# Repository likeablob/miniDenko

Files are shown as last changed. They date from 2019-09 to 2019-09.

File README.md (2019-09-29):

<p align="center">
  
</p>

# miniDenko - A portable messaging device
`miniDenko` (Denko = 電光 is from "an electric scoreboard" in Japanese) is a portable messaging device.

Or LED Matrix + ESP8266 + MPU6050 + Modern Web framework(Vue.js + Buefy) = A hackable LED messaging platform

<p align="center">
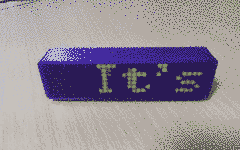
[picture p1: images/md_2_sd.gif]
  
</p>

## Features
- Edit & save your message and show it up instantly.(Sub-second booting)
  - Also supports Japanese characters thanks to [Arduino-misakiUTF16](https://github.com/Tamakichi/Arduino-misakiUTF16) lib written by [[Tamakichi]](https://github.com/Tamakichi) san.
- Easily connectable with Phones, Laptops, etc. via WiFi.
  - Supports `STA`, `AP`, `AP_STA` modes to collaborate with the devices.
- Made from easily-obtainable parts. (See [#BOM](#BOM))
- Its [portable and slim shape](./openscad/minidenko-case-body-opaque.stl) fits in your (large) pocket.

- And as a latest gadget should be, equipped with the **Type-C** charging port.

## Project structure
- [`pio/`](./pio) - code for the firmware(PlatformIO)
- [`pio/webui/`](./pio/webui) - code for the WebUI(Vue.js + Buefy)
- [`kicad/`](./kicad) - PCB design (KiCad)
- [`gerber/`](./gerber) - PCB gerber files (KiCad)
- [`openscad/`](./openscad) - models for the 3D-printable case. (OpenSCAD)

## Gallery
| | Descriptions |
| --- | --- |
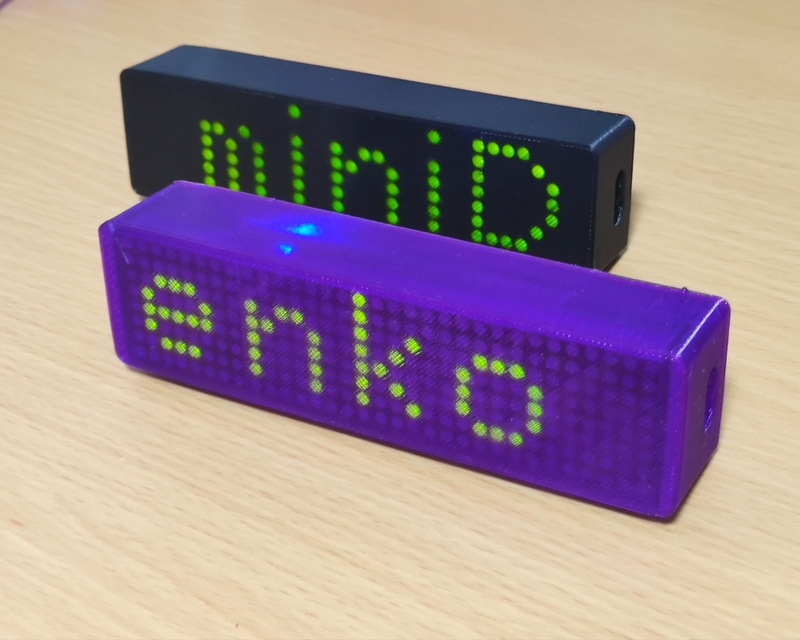
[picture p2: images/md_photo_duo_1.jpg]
|  | Front view |
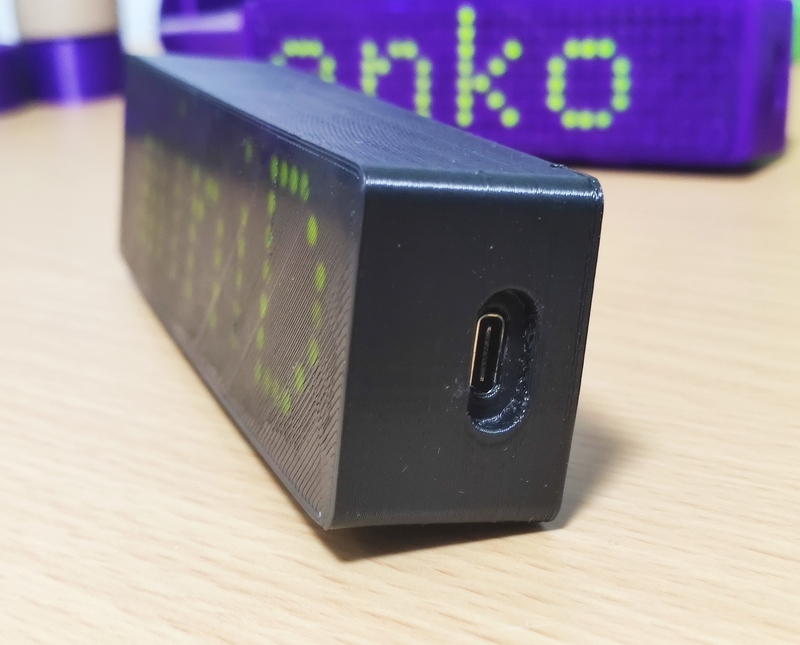
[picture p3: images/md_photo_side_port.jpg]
|  | Side view (Charging port) |
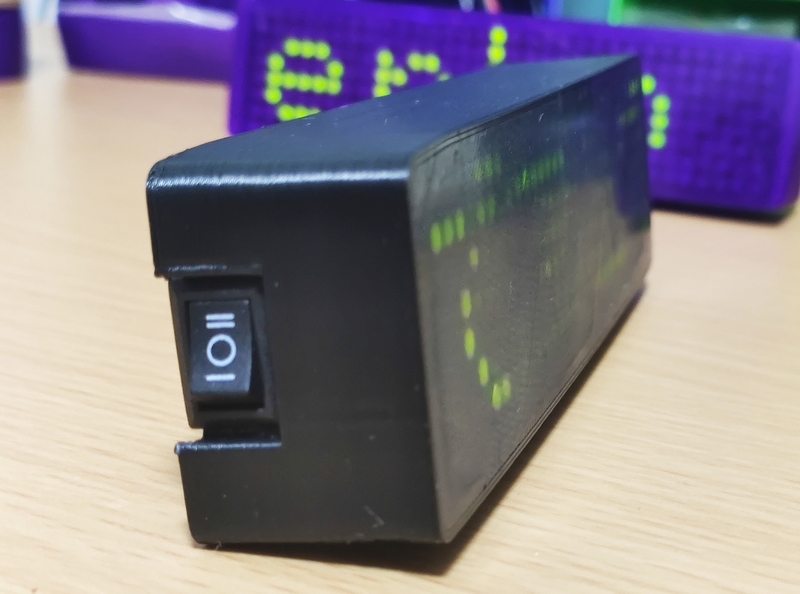
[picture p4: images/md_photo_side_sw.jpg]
|  | Side view (Power SW) |
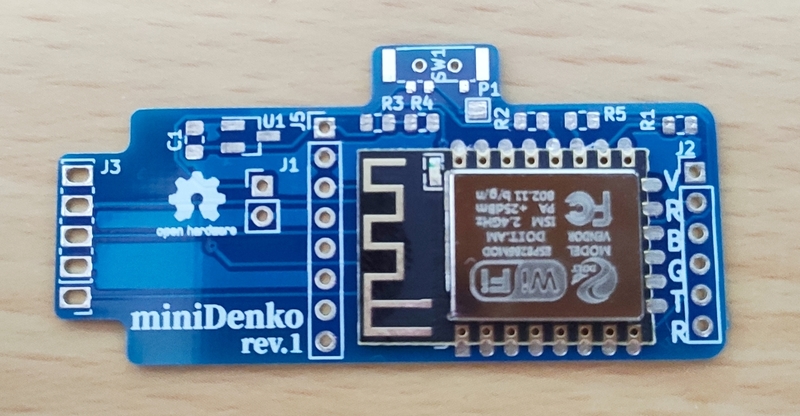
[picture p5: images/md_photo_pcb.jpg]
|  | PCB |
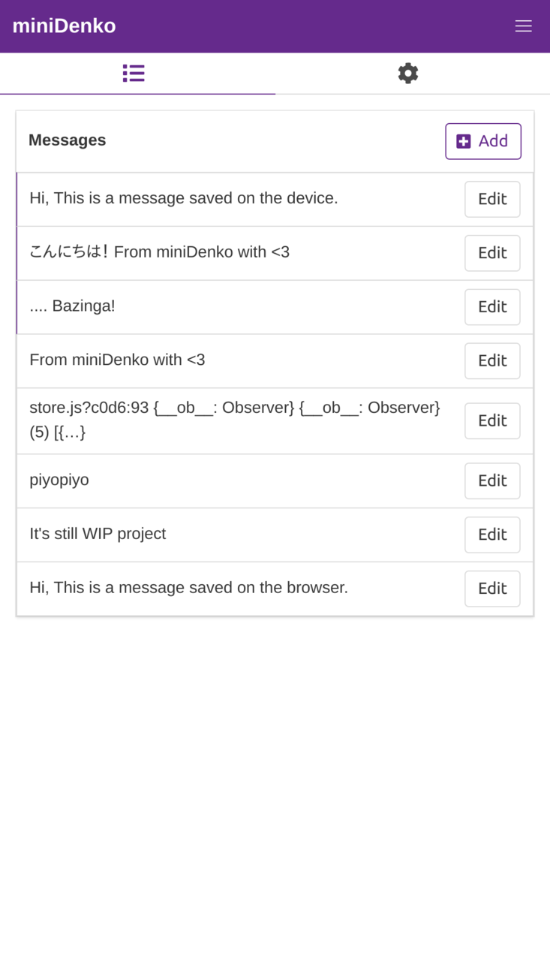
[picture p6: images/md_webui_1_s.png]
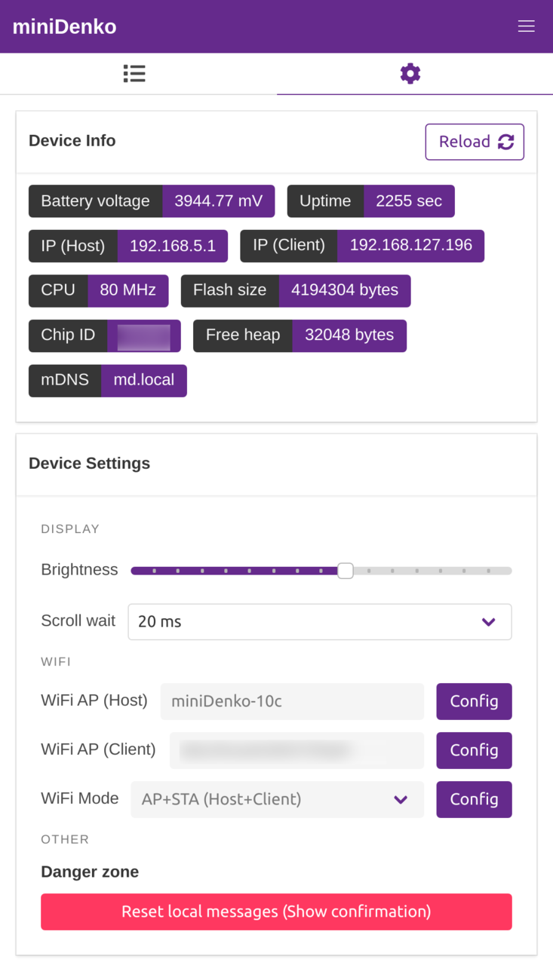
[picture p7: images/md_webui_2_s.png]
|   | Web UI |

## BOM
| Name | Quantity | Descriptions |
| --- | :---: | --- |
| ESP-12F (ESP8266 module) | 1 | |
| 32x8 LED matrix module (MAX7219) | 1 | |
| GY-521 (MPU6050 module) | 1 | 8 pins |
| 350mAh LiPo battery | 1 | 19x36x8.5 mm |
| Type-C LiPo charging board (TP4056) | 1 | 28x17.3 mm |
| 10k ohm resistor (0805_2012Metric) | 4 | |
| 33k ohm resistor (0805_2012Metric) | 1 | |
| 1uF ceramic capacitor (0805_2012Metric) | 1 | |
| 3.3V LDO xc6206p332mr (SOT-23) | 1 | |
| SPDT rocker switch (10x15 mm) | 1 | |
| M1.2 x 5 mm self tapping screw | 4 | |
| M2 x 6 mm self tapping screw | 2 | |

## Build instructions
https://hackaday.io/project/167747/instructions

## Refs
- https://www.thingiverse.com/thing:3876563
- https://hackaday.io/project/167747-minidenko
  
## License
MIT

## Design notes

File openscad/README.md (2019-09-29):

# miniDenko/shell

<p align="center">
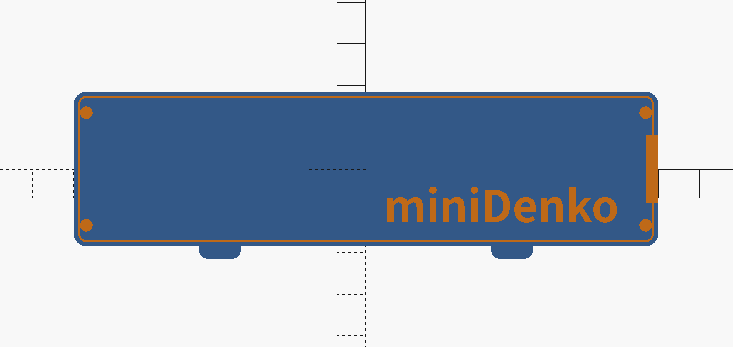
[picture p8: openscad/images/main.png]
  
</p>

The outer shell for miniDenko.

## Dependencies
- [OskarLinde]'s [scad-utils](https://github.com/OskarLinde/scad-utils)
- openscad-nightly (`20181009T230242.gitf3de0e27+2416.1`)

## Build
```sh
$ git submodule update --init --recursive # or git clone --recursive
$ make -j4
```

## Variants/Accessories
### [minidenko-case-body-opaque](./minidenko-case-body-opaque.stl)
- For opaque fillaments.
- Print settings: PLA, 0.2mm, 180 ℃
  - 210 ℃ for the first layer since the front panel's thickness is 0.3 mm. (`BODY_BOTTOM_Z = 0.3`;)

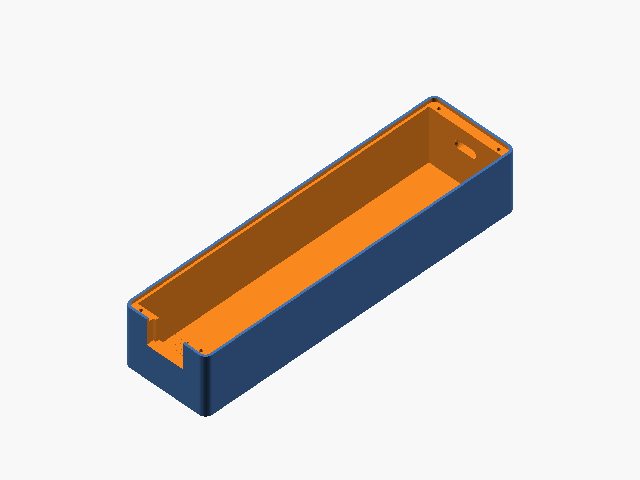
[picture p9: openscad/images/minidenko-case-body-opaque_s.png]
minidenko-case-body-opaque


### [minidenko-case-body-transparent](./minidenko-case-body-transparent.stl)
- For semi-transparent fillaments.
- Print settings: PLA, 0.2mm, 180 ℃

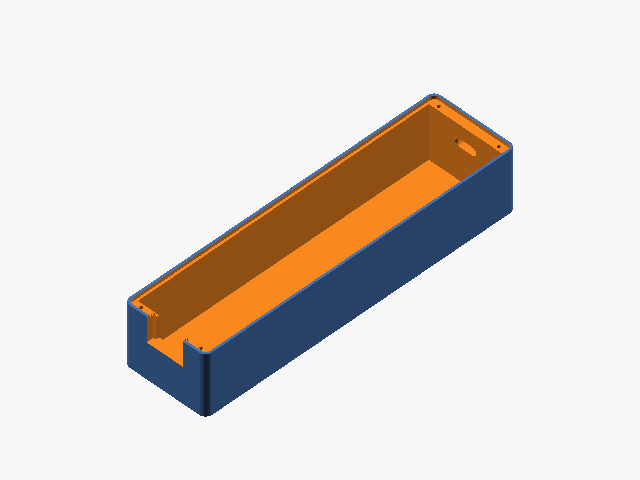
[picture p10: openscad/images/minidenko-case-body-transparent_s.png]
minidenko-case-body-transparent


### [minidenko-case-backpanel-a](./minidenko-case-backpanel-a.stl)
- A backpanel (lid) - Type A
- Print settings: PLA, 0.2mm, 180 ℃

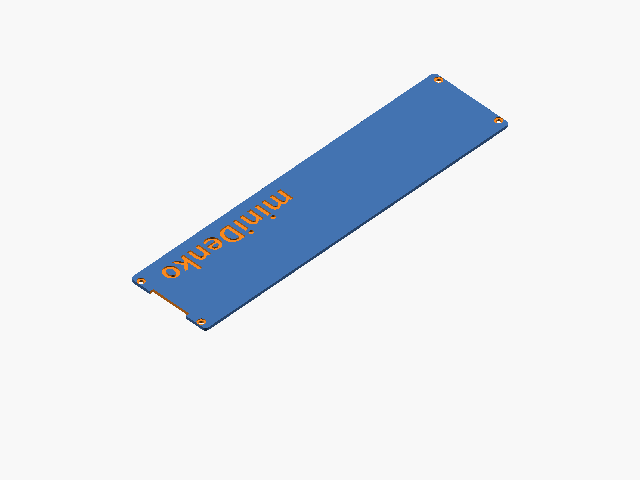
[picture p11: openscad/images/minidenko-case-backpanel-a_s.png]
minidenko-case-backpanel-a


### [minidenko-port-holder_s](./minidenko-port-holder.stl)
- For fixing the LiPo charging board.
- Print settings: PLA, 0.2mm, 180 ℃

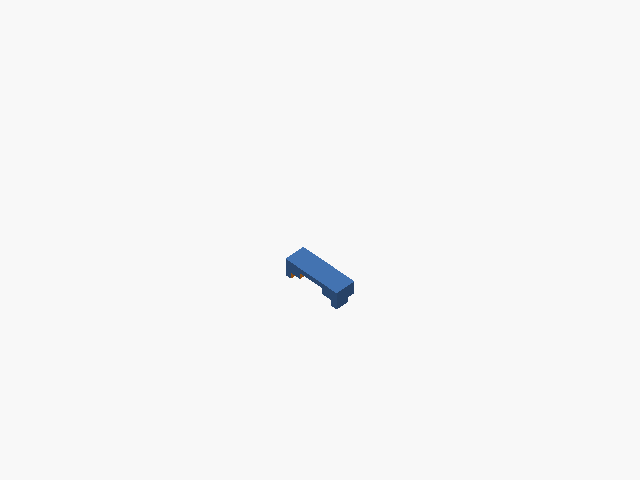
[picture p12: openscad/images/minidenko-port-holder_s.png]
minidenko-port-holder


## License
MIT

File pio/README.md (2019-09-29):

# miniDenko/firmware
It's built on top of [esp8266/Arduino](https://github.com/esp8266/Arduino).

## Prerequisites
- Install [PlatformIO](https://platformio.org/)

## Build
- `Ctrl+Alt+B` in your editor, or 
```bash
$ pio run
```

## Upload
- `Ctrl + Alt + U` in your editor, or 
```bash
$ pio run -t upload
```
- ***Tips:*** Don't forget to comment out the lines below to do ISP(UART) programming.
```bash
# platform.ini
upload_port = ${env:main.device_name}.local
upload_protocol = espota
```
### ISP port (J2) pin definitions:
```
V: 5V (LDO_IN)
R: ESP_RESET: RST pin
B: ESP_BOOT: GPIO0 pin
G: GND
T: ESP_TXD: TX pin
R: ESP_RXD: RX pin
```

## Build WebUI
- All the assets are gziped and included as C headers.
```bash
src/webui/app.js.gz.h
src/webui/favicon.ico.gz.h
src/webui/manifest.json.gz.h
src/webui/index.html.gz.h
...
```
- See [webui/README.md](./webui)

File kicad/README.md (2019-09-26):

# miniDenko/PCB

<p align="center">
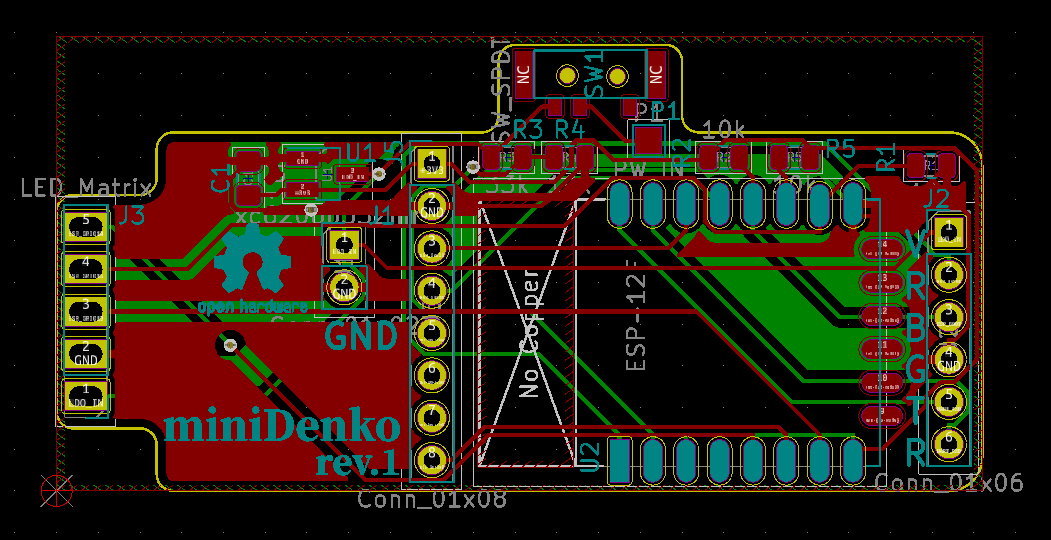
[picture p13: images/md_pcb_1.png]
  
</p>

## Prerequisites
- Install [KiCAD](https://platformio.org/) v5.0.1

## Credits
- [ESP-12E.kicad_mod](./lib_ext/ESP-12E.kicad_mod): borrowed from [jdunmire/kicad-ESP8266](https://github.com/jdunmire/kicad-ESP8266/tree/70e6530de5e3cae4ae77a4bca7d73b20a0af6baf)
- [MSK12C02.kicad_mod](./lib_ext/MSK12C02.kicad_mod): borrowed from [ElectronicCats/ElectronicCats-KiCad-Libraries](https://github.com/ElectronicCats/ElectronicCats-KiCad-Libraries/tree/df452181bf0b37c41caa9d8791b5432d5b44f4c0)

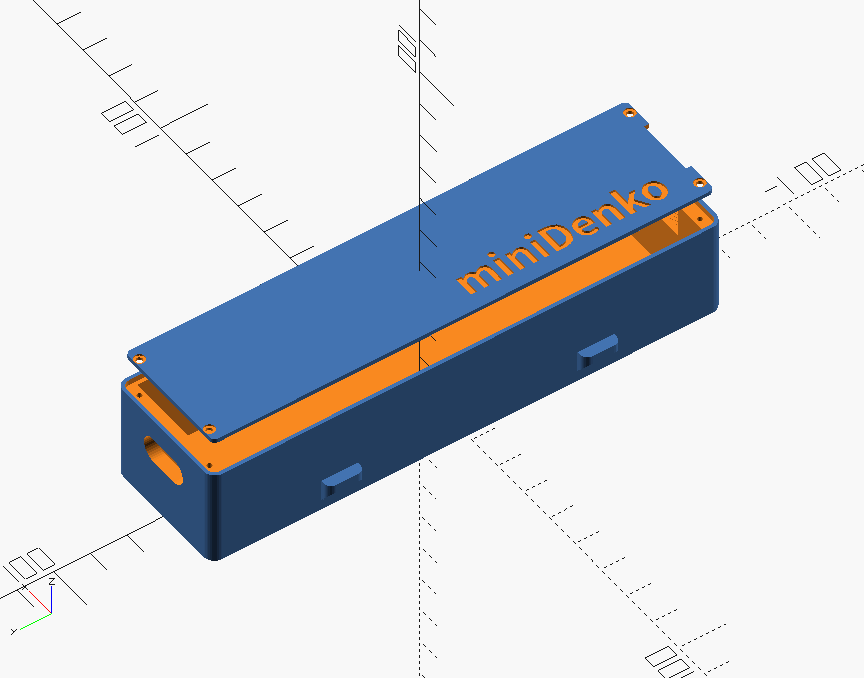
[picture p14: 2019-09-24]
openscad/images/main-rot.png

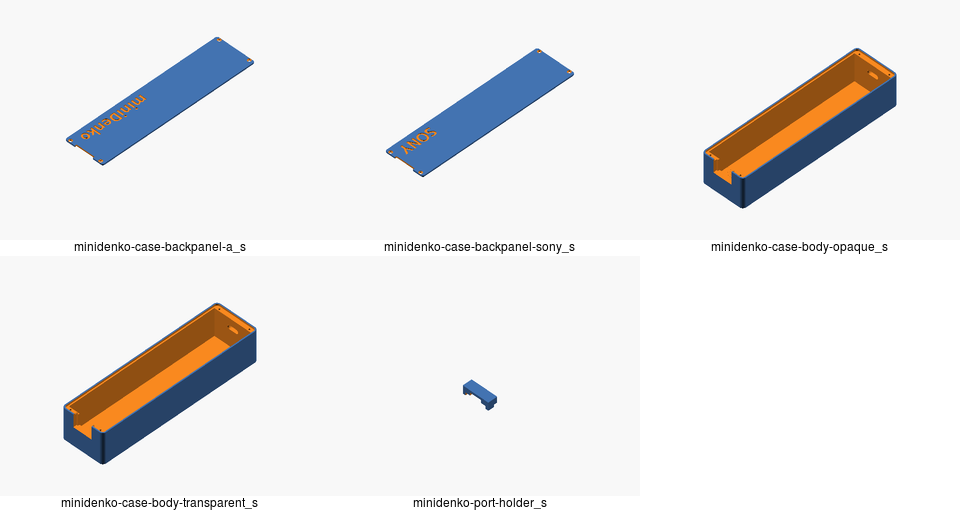
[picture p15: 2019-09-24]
openscad/images/models.png

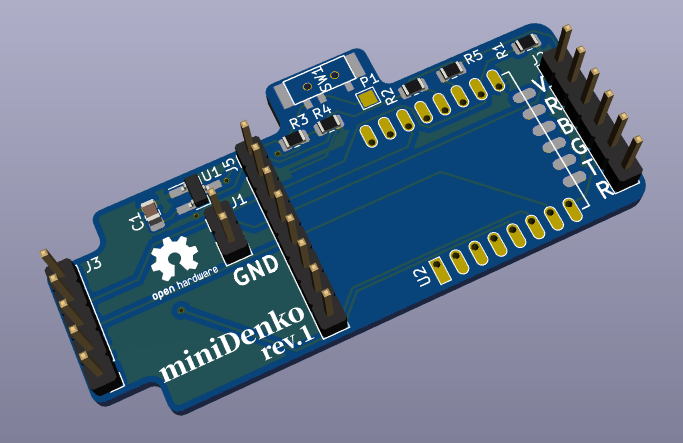
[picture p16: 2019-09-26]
images/md_pcb_2.png

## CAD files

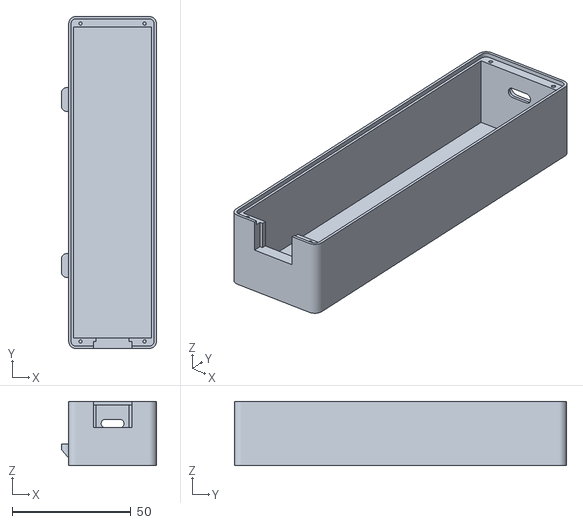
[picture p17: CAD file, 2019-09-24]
openscad/minidenko-case-body-transparent.stl
40.0 x 140.0 x 27.0

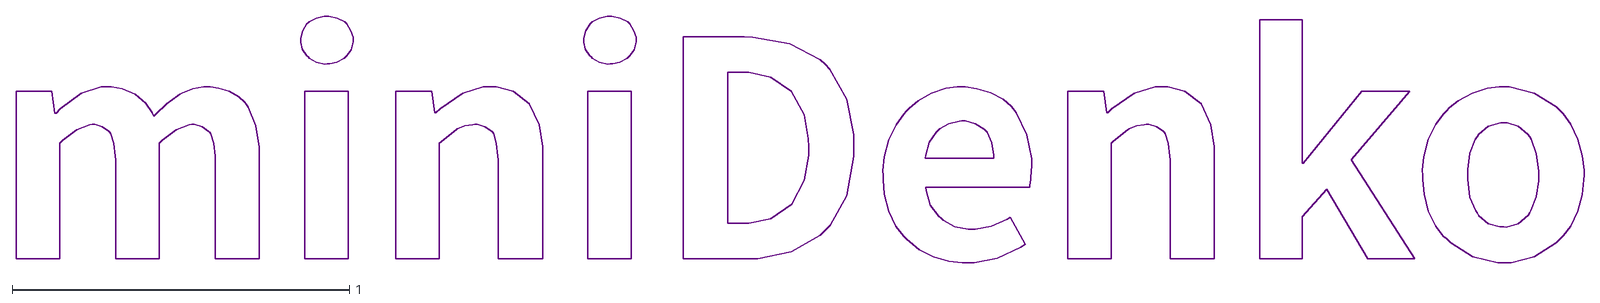
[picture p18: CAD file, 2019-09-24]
openscad/minidenko-logo-mono.dxf
4.65 x 0.732

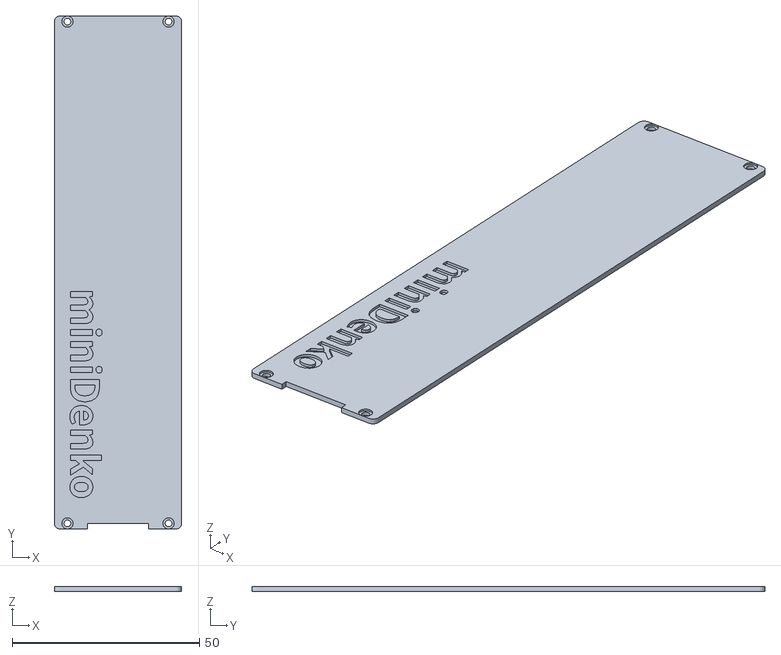
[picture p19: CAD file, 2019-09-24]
openscad/minidenko-case-backpanel-a.stl
34.0 x 137.0 x 1.21

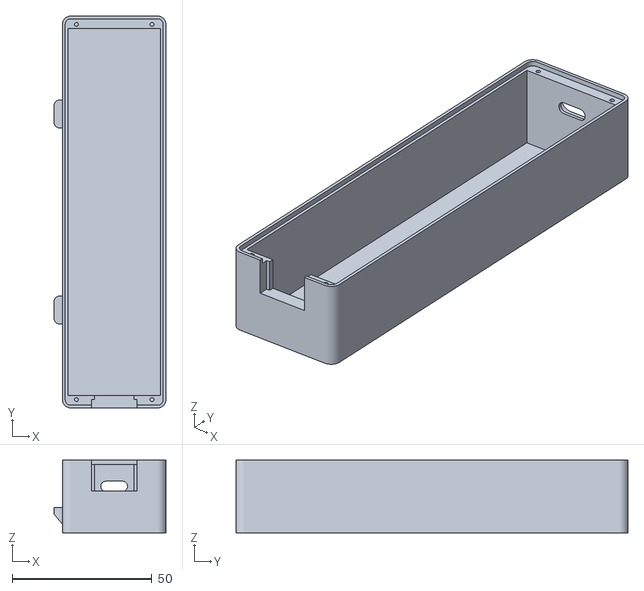
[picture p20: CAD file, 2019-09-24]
openscad/minidenko-case-body-opaque.stl
40.0 x 140.0 x 25.9

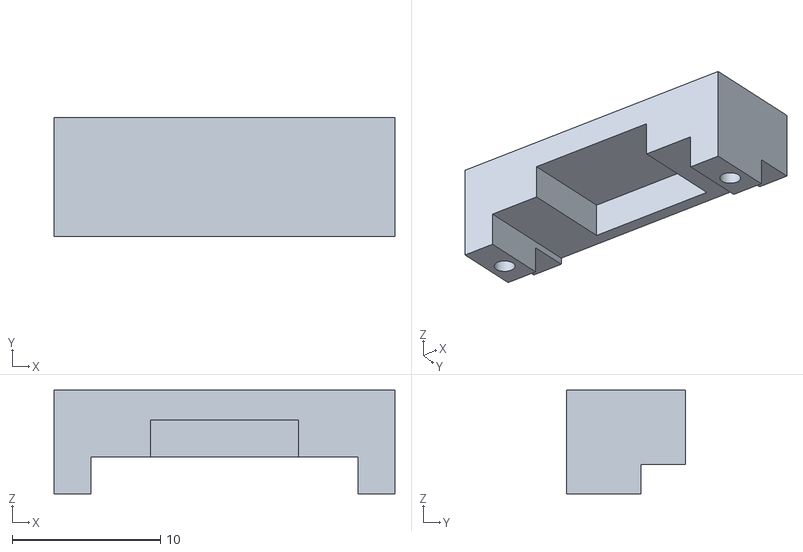
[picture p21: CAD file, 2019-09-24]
openscad/minidenko-port-holder.stl
23.0 x 8.00 x 7.00

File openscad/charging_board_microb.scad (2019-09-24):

USB_X = 18;
USB_Y = 15;
module USB_BOARD_DIF(scZ) {

  // BOARD
  difference() {
    translate([0, 0, 1.5/2])
    cube(size=[USB_X, USB_Y, 1.5], center=true);

    copy_mirror([1,0,0])
    translate([USB_X/2-3.3/2-1, -USB_Y/2+3.3/2+4, 0])
    cylinder(d=3.3, h=10, center=true);
  }

  // PORT
  USB_P_Y_OFFSET = 10;
  USB_P_Y = 8+USB_P_Y_OFFSET;
  translate([0, USB_Y/2-USB_P_Y/2 + USB_P_Y_OFFSET, 1.5-0.3]){
    hull() {
      //top
      translate([0, 0, 3.2])
      cube(size=[6.2+0.2, USB_P_Y, 0.01], center=true);

      // middle
      translate([0, 0, 1.55])
      cube(size=[8.0+0.2, USB_P_Y, 0.5], center=true);

      //bottom
      translate([0, 0, 0])
      cube(size=[5.2+1, USB_P_Y, 0.01], center=true);
    }
  }

  //screws
  copy_mirror([1,0,0])
  translate([USB_X/2-3.3/2-1, -USB_Y/2+3.3/2+4, -scZ/2])
  cylinder(d=2.2, h=scZ, center=true);
}

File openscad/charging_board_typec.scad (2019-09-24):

USB_TYPEC_BOARD_X = 17.1;
USB_TYPEC_BOARD_Y = 28.1;
USB_TYPEC_BOARD_Z = 1.0;

module USB_TYPEC_BOARD(diff=false) {
  translate([0, -USB_TYPEC_BOARD_Y/2, 0])   
  linear_extrude(height=USB_TYPEC_BOARD_Z, center=!true, convexity=10, twist=0) 
  square(size=[USB_TYPEC_BOARD_X, USB_TYPEC_BOARD_Y], center=true);

  translate([0, 1.5, USB_TYPEC_BOARD_Z])
  translate([0, -7.3, 3/2])
  rotate([-90, 0, 0]) 
  linear_extrude(height=diff ? 20 : 7.3, center=!true, convexity=10, twist=0)
  hull(){
    offset(r= diff ? 0.3 : 0)
    mirror_x()
    translate([9/2-3/2, 0, 0])
    circle(d=3);
  }
}

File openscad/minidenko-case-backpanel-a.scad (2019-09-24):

$fn=40;

include <minidenko-case-base.scad>

BODY_BOTTOM_Z = 1.4;

translate([0, 0, 10]) 
difference(){
  backPanel(inset=0.5, h=1.2);
  screws(1.8);
  translate([0, 0, 9-0.4])
  screws(3);

  translate([-15, -2, BODY_Z-0.6]) 
  linear_extrude(height=1, center=false, convexity=10, twist=0)
  rotate([0, 0, -90])
  resize([55, 0, 0], auto=true)
  import("minidenko-logo-mono.dxf");
}

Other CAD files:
openscad/minidenko-case-base.scad
openscad/minidenko-case-body-opaque.scad
openscad/minidenko-case-body-transparent.scad
openscad/minidenko-port-holder.scad

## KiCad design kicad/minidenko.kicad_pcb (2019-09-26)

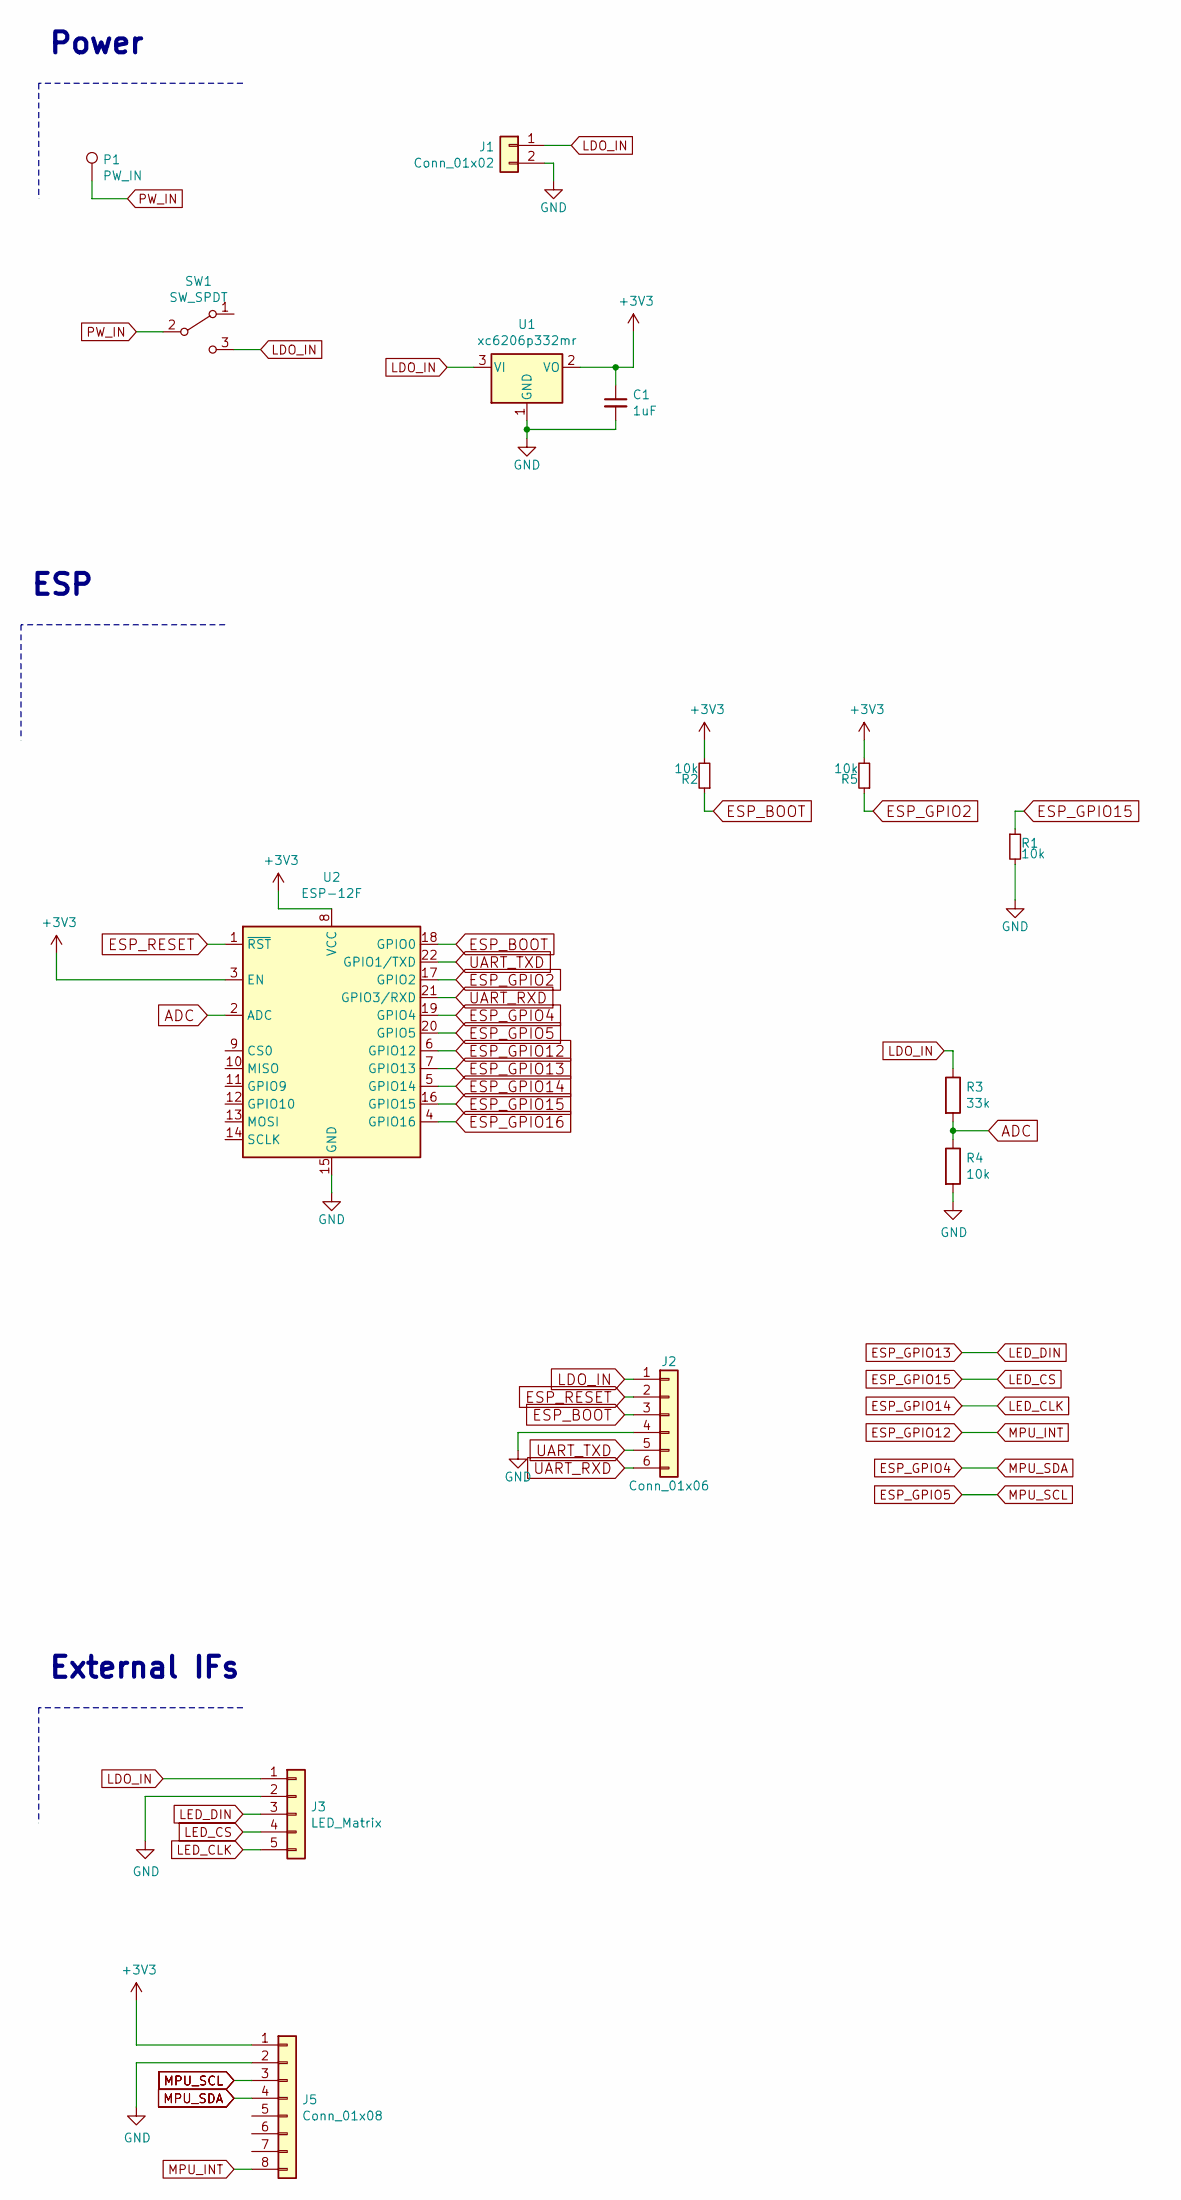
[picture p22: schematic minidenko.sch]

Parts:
C1: 1uF; C_0805_2012Metric_Pad1.15x1.40mm_HandSolder
J1: Conn_01x02; PinHeader_1x02_P2.54mm_Vertical
J2: Conn_01x06; PinHeader_1x06_P2.54mm_Vertical
J3: LED_Matrix; LED_Matrix_1x05_P2.54mm
J5: Conn_01x08; PinHeader_1x08_P2.54mm_Vertical
P1: PW_IN; TestPoint_Pad_1.5x1.5mm
R1, R2, R4, R5: 10k; R_0805_2012Metric
R3: 33k; R_0805_2012Metric
SW1: SW_SPDT; MSK12C02
U1: xc6206p332mr; SOT-23_Handsoldering
U2: ESP-12F; ESP-12E

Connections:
+3V3: C1.1, J5.1, R2.2, R5.2, U1.2 (VO), U2.3 (EN), U2.8 (VCC)
ADC: R3.2, R4.1, U2.2 (ADC)
ESP_BOOT: J2.3, R2.1, U2.18 (GPIO0)
ESP_GPIO2: R5.1, U2.17 (GPIO2)
ESP_GPIO4: J5.4, U2.19 (GPIO4)
ESP_GPIO5: J5.3, U2.20 (GPIO5)
ESP_GPIO12: J5.8, U2.6 (GPIO12)
ESP_GPIO13: J3.3, U2.7 (GPIO13)
ESP_GPIO14: J3.5, U2.5 (GPIO14)
ESP_GPIO15: J3.4, R1.1, U2.16 (GPIO15)
ESP_GPIO16: U2.4 (GPIO16)
ESP_RESET: J2.2, U2.1 (~RST)
GND: C1.2, J1.2, J2.4, J3.2, J5.2, R1.2, R4.2, U1.1 (GND), U2.15 (GND)
LDO_IN: J1.1, J2.1, J3.1, R3.1, SW1.3 (C), U1.3 (VI)
PW_IN: P1.1, SW1.2 (B)
UART_RXD: J2.6, U2.21 (GPIO3/RXD)
UART_TXD: J2.5, U2.22 (GPIO1/TXD)

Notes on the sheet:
ESP
Power
External IFs

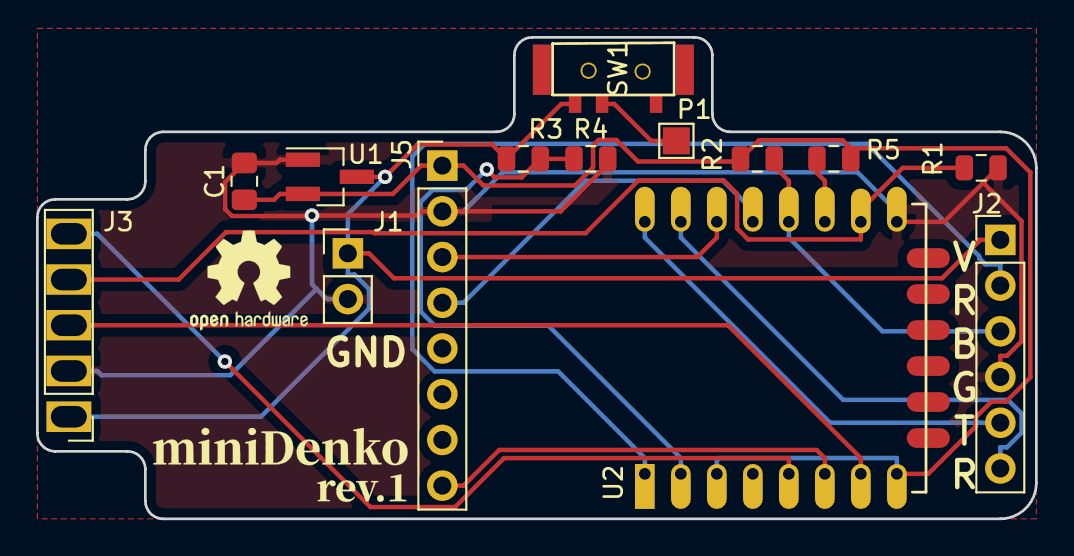
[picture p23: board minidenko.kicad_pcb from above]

Board: 2 copper layers, 55.5 x 26.8 mm, 17 parts (1 on the bottom side), 16 nets.

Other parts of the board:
G1: LOGO; logo-minidenko-rev1
G2: OSHW-Logo2_7.3x6mm_SilkScreen
G3: LOGO; gomi_8x8

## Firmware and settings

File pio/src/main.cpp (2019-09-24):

#include <Arduino.h>
#include <LedControl.h>

extern "C" {
#include "user_interface.h"
}

#include "config.h"
#include "denko.h"
#include "motion.h"
#include "ota.h"
#include "server.h"
#include "settings.h"
#include "wifi.h"

#include "DNSServer.h"

#define DNS_PORT 53
DNSServer dnsServer;

SettingsService settingsService;
LedControl lc = LedControl(PIN_LED_DATA, PIN_LED_CLK, PIN_LED_CS, NUM_DISP);
Denko denko(lc);

void setup() {
    Serial.begin(115200);
    Serial.println("Booting");

    denko.begin();
    OTAService::begin();
    if(!settingsService.begin()) {
        denko.drawStr("Reset");
        delay(1000);
        settingsService.forceReset();
    }
    MotionService::begin();
    ServerService::begin();
    WiFiService::switchMode(settingsService.wifiMode, settingsService.hApName,
                            settingsService.hApPass, settingsService.cApName,
                            settingsService.cApPass);

    // dnsServer.start(DNS_PORT, "*", apIP);
    Serial.println("Ready");
    Serial.print("IP address: ");
    Serial.println(WiFi.localIP());

    DenkoMessage msg("No suitable message found.", false, true);
    settingsService.nextMessage(msg);
    denko.drawMsg(msg);
    denko.setBrightness(settingsService.brightness);
    denko.setRefreshInterval(settingsService.scrollWait);
}

void loop() {
    // dnsServer.processNextRequest();
    OTAService::handle();
    ServerService::handle();
    MotionService::handle();
    denko.handle();
}

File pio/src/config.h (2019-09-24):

#ifndef INCLUDE_GUARD_CONFIG_H
#define INCLUDE_GUARD_CONFIG_H

#define BOARD_REVISION_V1_0

#ifdef BOARD_REVISION_V1_0
#define BOARD_REVISION "v1.0"
#endif

// PIN definitions
#define PIN_LED_DATA 13
#define PIN_LED_CLK 14
#define PIN_LED_CS 15

#define PIN_MPU_SDA 4
#define PIN_MPU_SCL 5
#define PIN_MPU_INT 12

#endif // INCLUDE_GUARD_CONFIG_H

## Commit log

2019-09-26 Add PCB files
    [minidenko-B.Cu.gbr, minidenko-B.Mask.gbr, minidenko-B.Paste.gbr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]
2019-09-26 Modify README.md - Add BOM - Minor tweak
2019-09-26 Modify openscad/README - Add print settings
2019-09-27 Fix validation for a void message
    [settings.cpp]
